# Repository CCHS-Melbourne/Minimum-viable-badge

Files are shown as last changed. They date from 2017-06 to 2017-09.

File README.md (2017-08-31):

Minimum Viable Badge - Just the facts.
=============

This project is designed to be the absolute minimum number of components to do a badge.

[Schematic Design](Minimum-viable-schematic.pdf?raw=true "Schematic")

FEATURES
--------

* ESP32 based.
* CP2102 USB to serial.
* eInk Display.

CREDITS
------------

Made at hackmelbourne.org!

This project was designed by the 2018 linux.conf.au Open Hardware Team!
 - [Bob Powers](https://github.com/rdpowers)
 - [John Spencer](https://github.com/mage0r)
 - [Angus Gratton](https://github.com/projectgus)
 - [Andy Gelme](https://github.com/geekscape)
 - [Jon Oxer](https://github.com/jonoxer)
 - [Mark Wolfe](https://github.com/wolfeidau)

SPECIAL THANKS
------------

To the HackMelbourne (CCHS, http://hackmelbourne.org) community of Melbourne, Australia.

To all other open-source developers whose countless hours supported every other aspect of this design.

DISTRIBUTION
------------
The specific terms of distribution of this project are governed by the
license referenced below. Please contact the copyright owner if you wish to modify the board for distribution. Please utilize this design for personal or research projects. Please acknowledge all contributors.

LICENSE
-------
Licensed under the TAPR Open Hardware License (www.tapr.org/OHL).
The "license" sub-folder also contains a copy of this license in plain text format.

Copyright John Spencer, Bob Powers, Angus Gratton, Andy Gelme, Jon Oxer, Mark Wolfe 2017

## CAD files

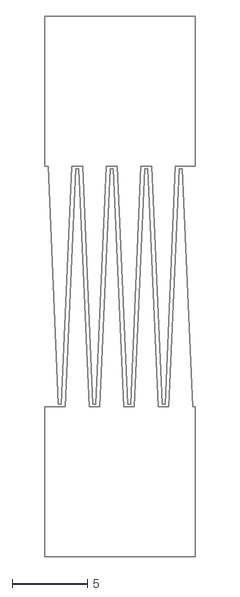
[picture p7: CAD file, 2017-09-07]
models/short-button.dxf
10.0 x 36.0

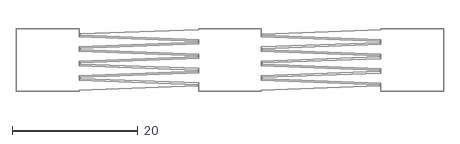
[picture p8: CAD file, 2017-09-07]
models/long-button.dxf
68.0 x 10.0

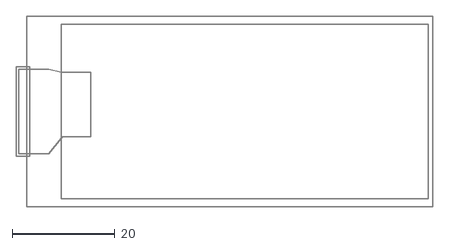
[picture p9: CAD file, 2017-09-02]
models/eink.2.0.dxf
81.1 x 37.0

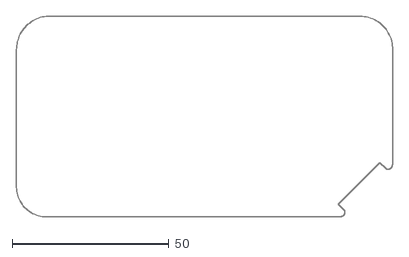
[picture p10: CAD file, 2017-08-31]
models/outline.2.0.dxf
120.0 x 64.0

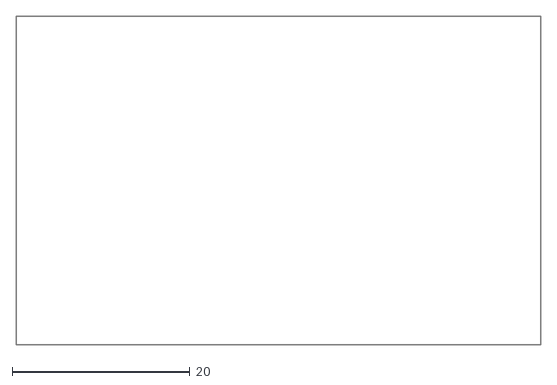
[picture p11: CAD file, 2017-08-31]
models/battery.2.0.dxf
59.0 x 37.0

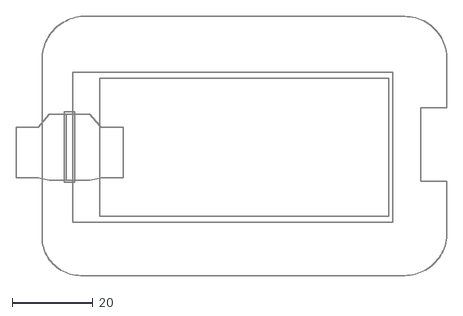
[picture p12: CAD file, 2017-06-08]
models/outline.dxf
106.4 x 64.0

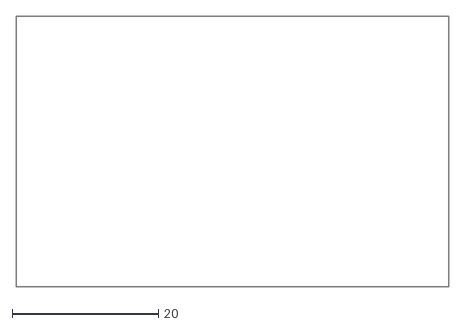
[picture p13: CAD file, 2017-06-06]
models/small Battery.dxf
59.0 x 37.0

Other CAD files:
models/outline-2.skp
models/outline.skp

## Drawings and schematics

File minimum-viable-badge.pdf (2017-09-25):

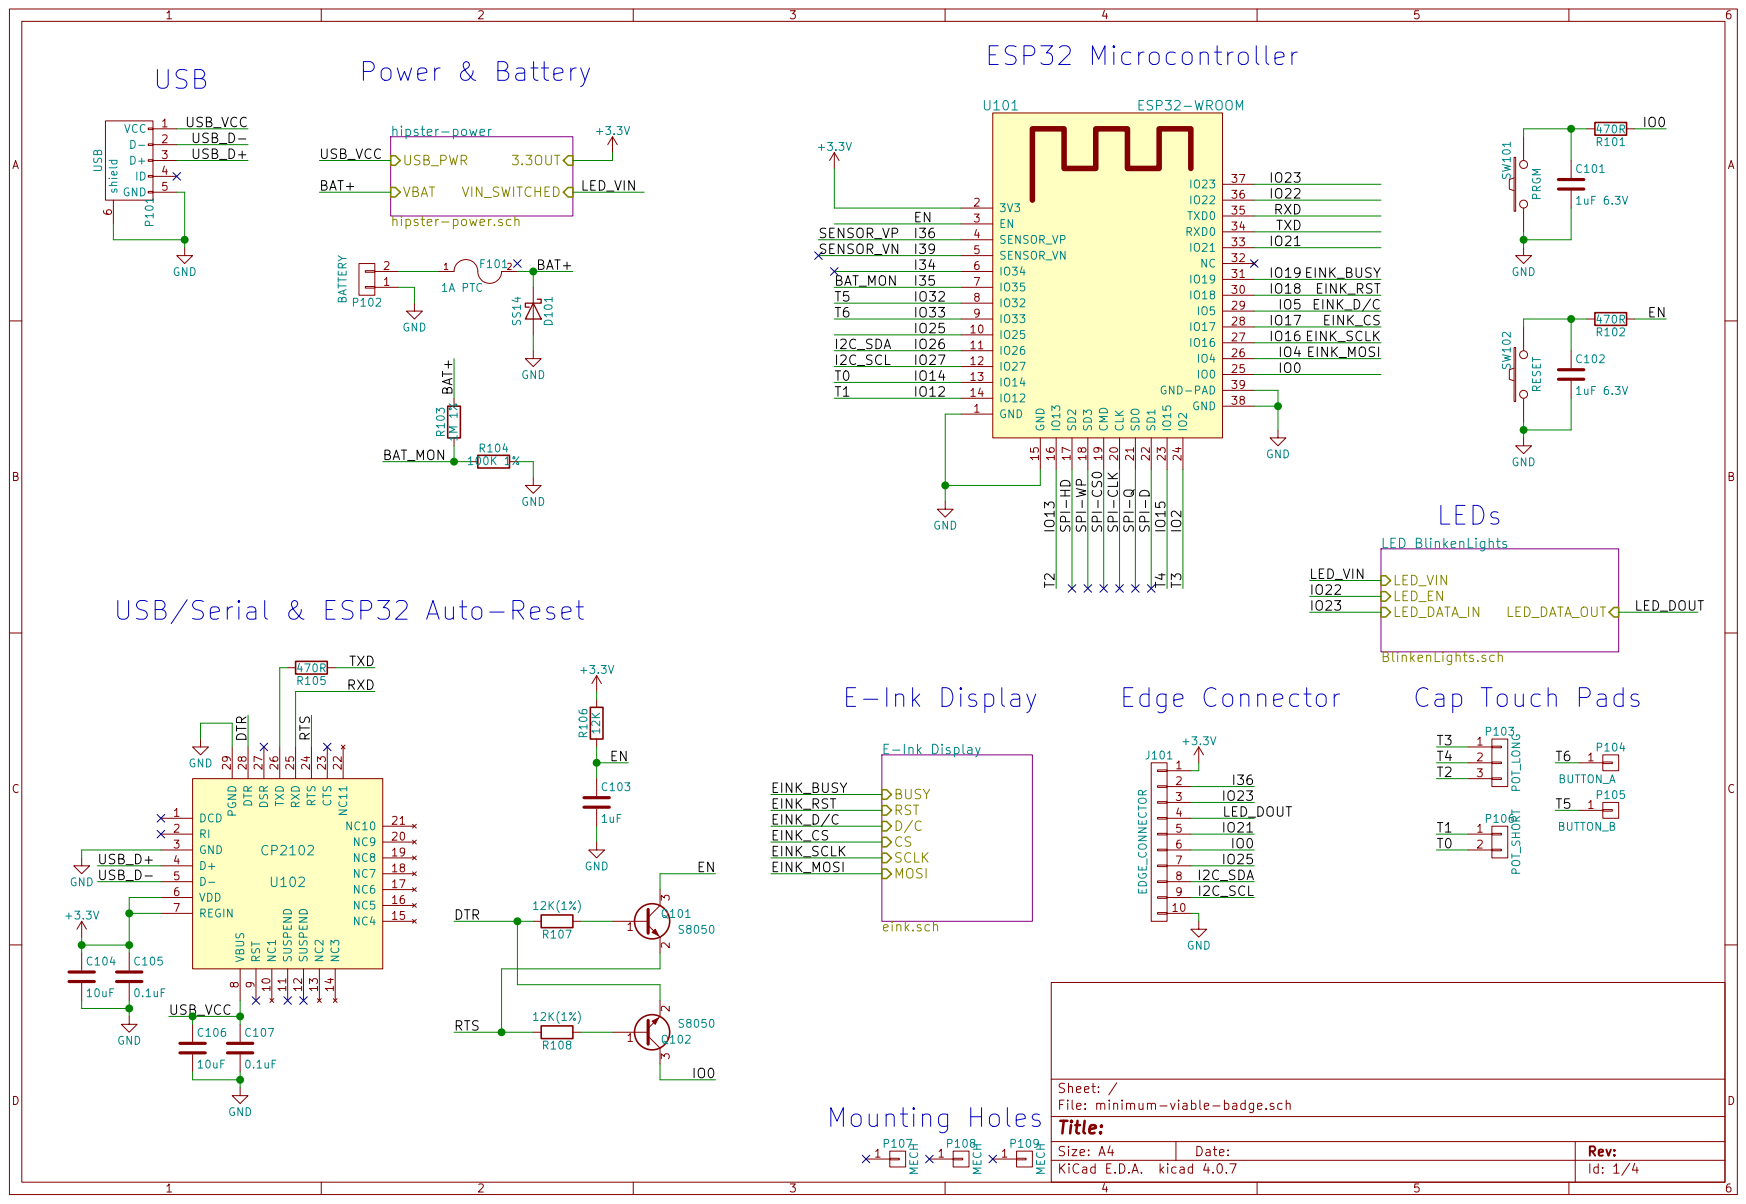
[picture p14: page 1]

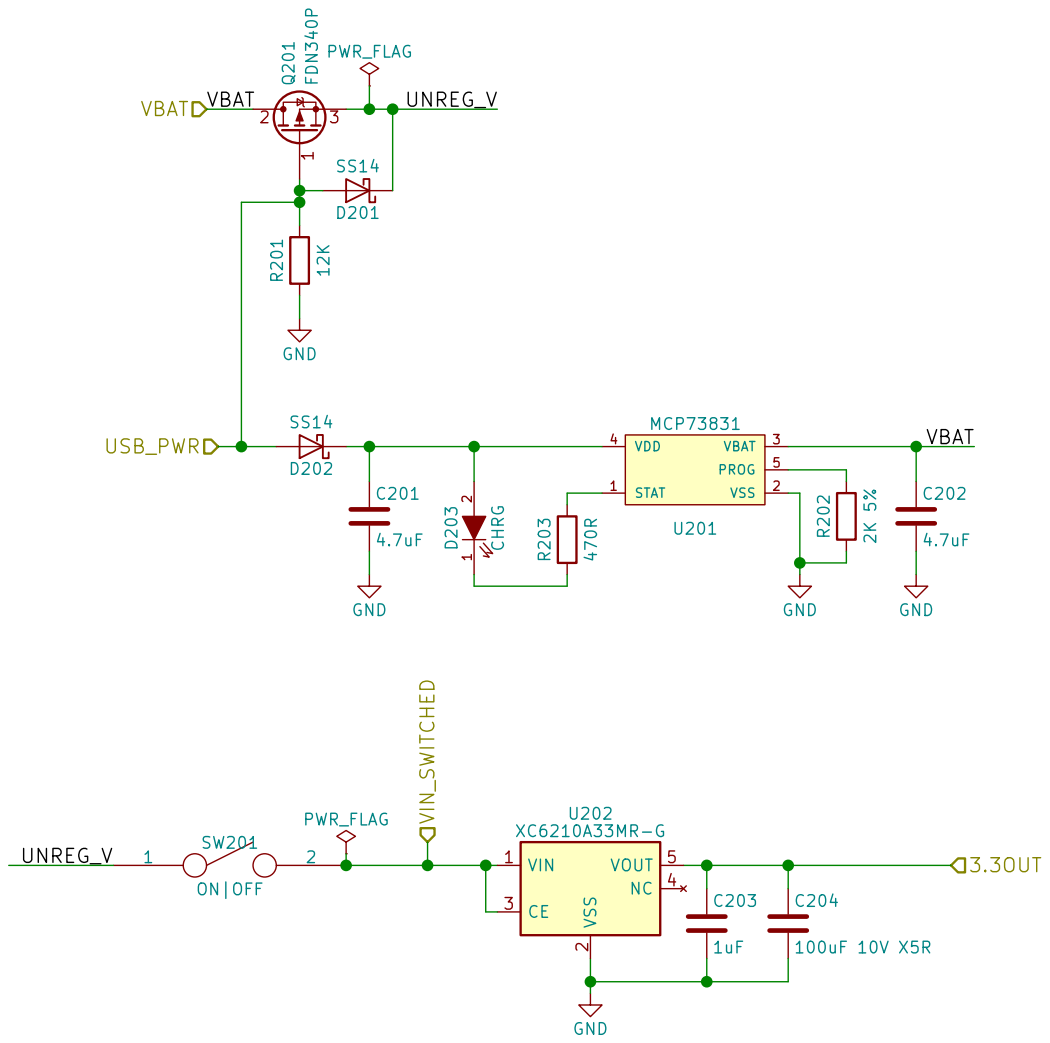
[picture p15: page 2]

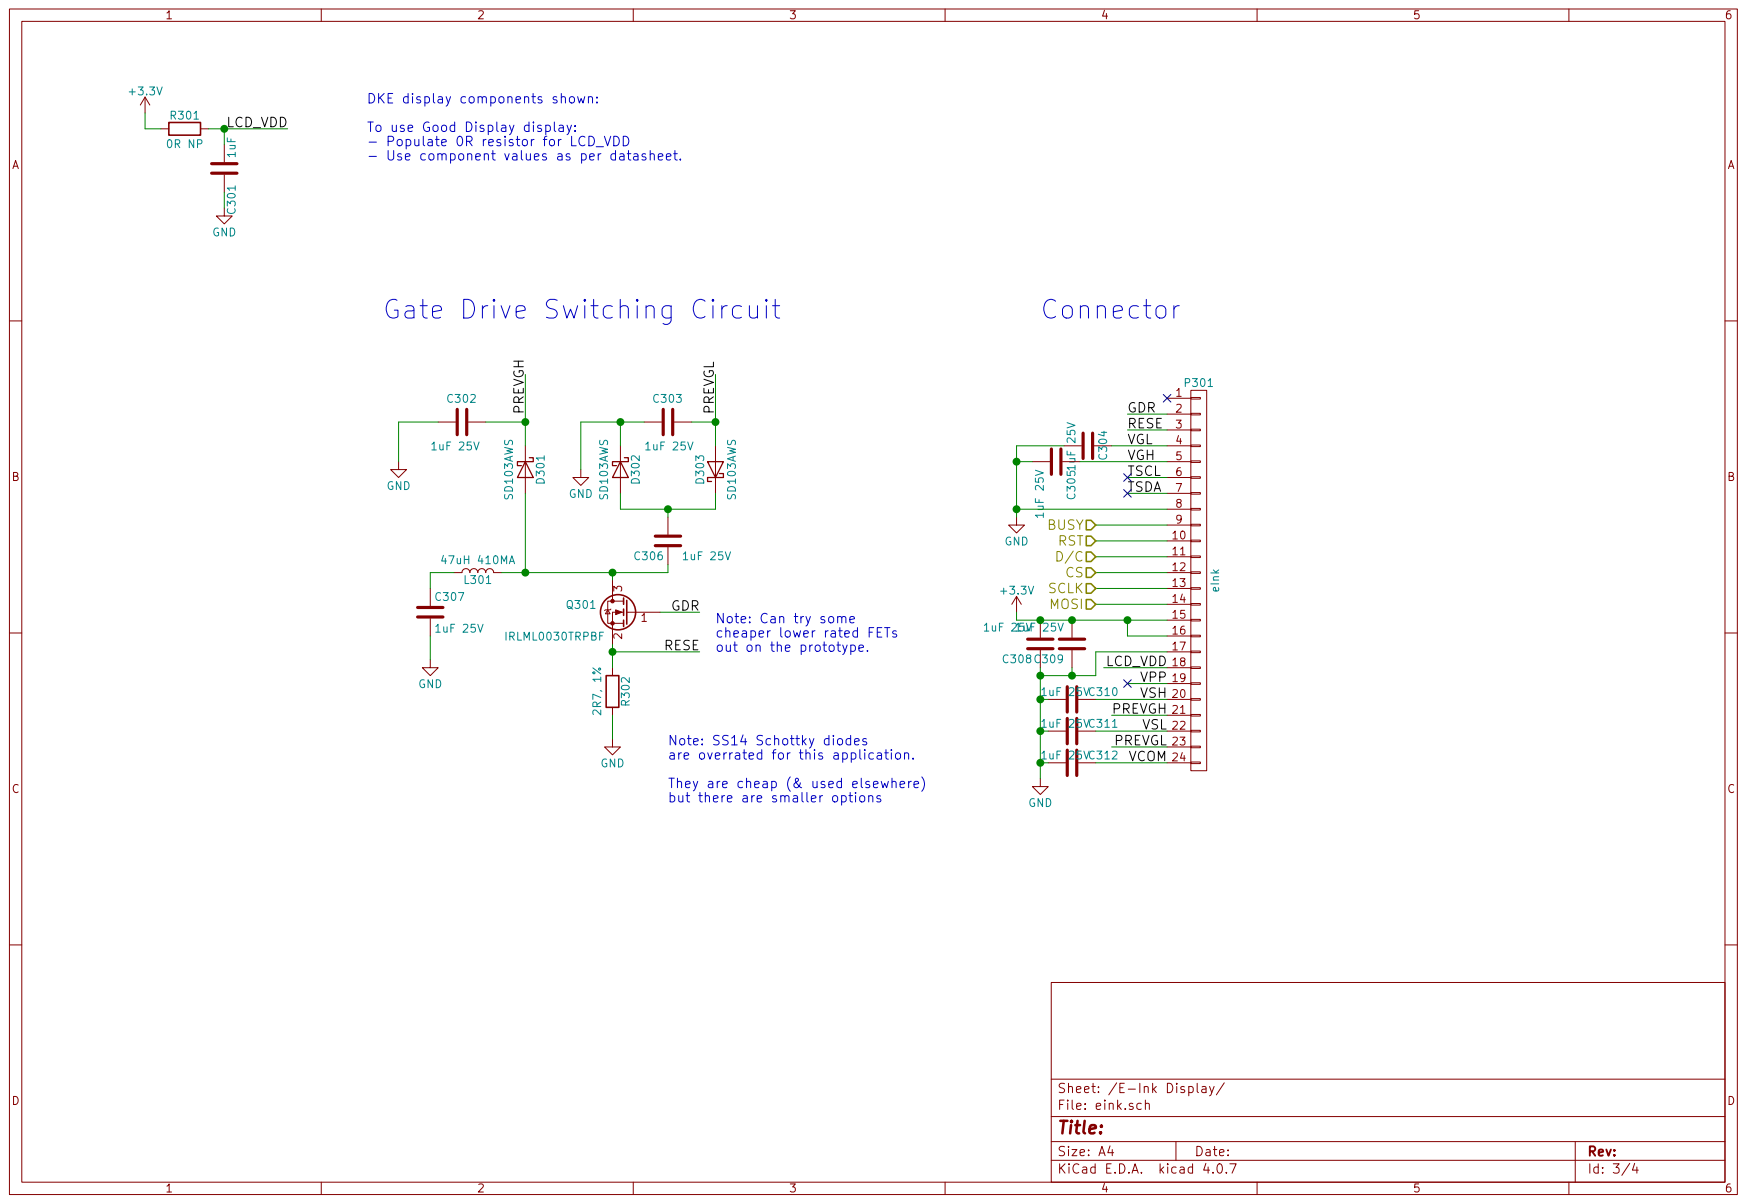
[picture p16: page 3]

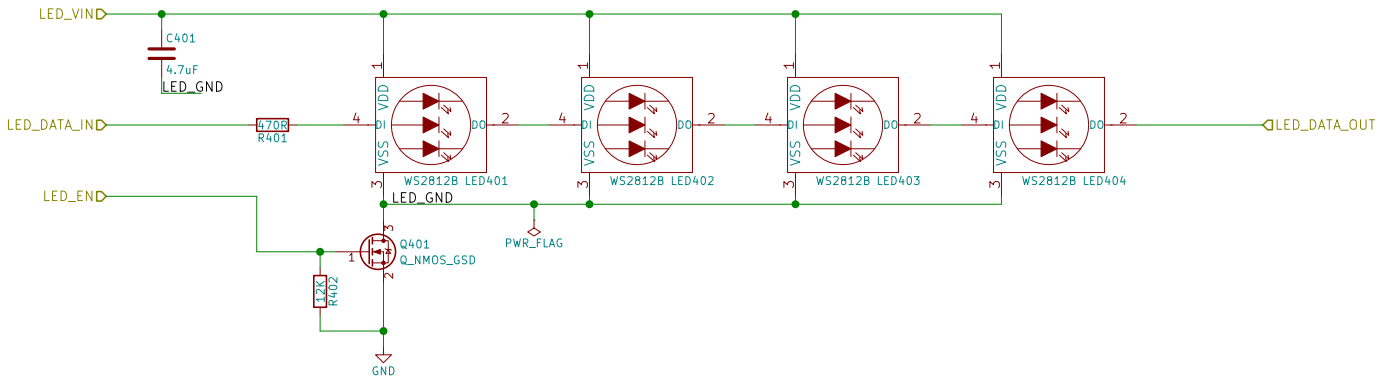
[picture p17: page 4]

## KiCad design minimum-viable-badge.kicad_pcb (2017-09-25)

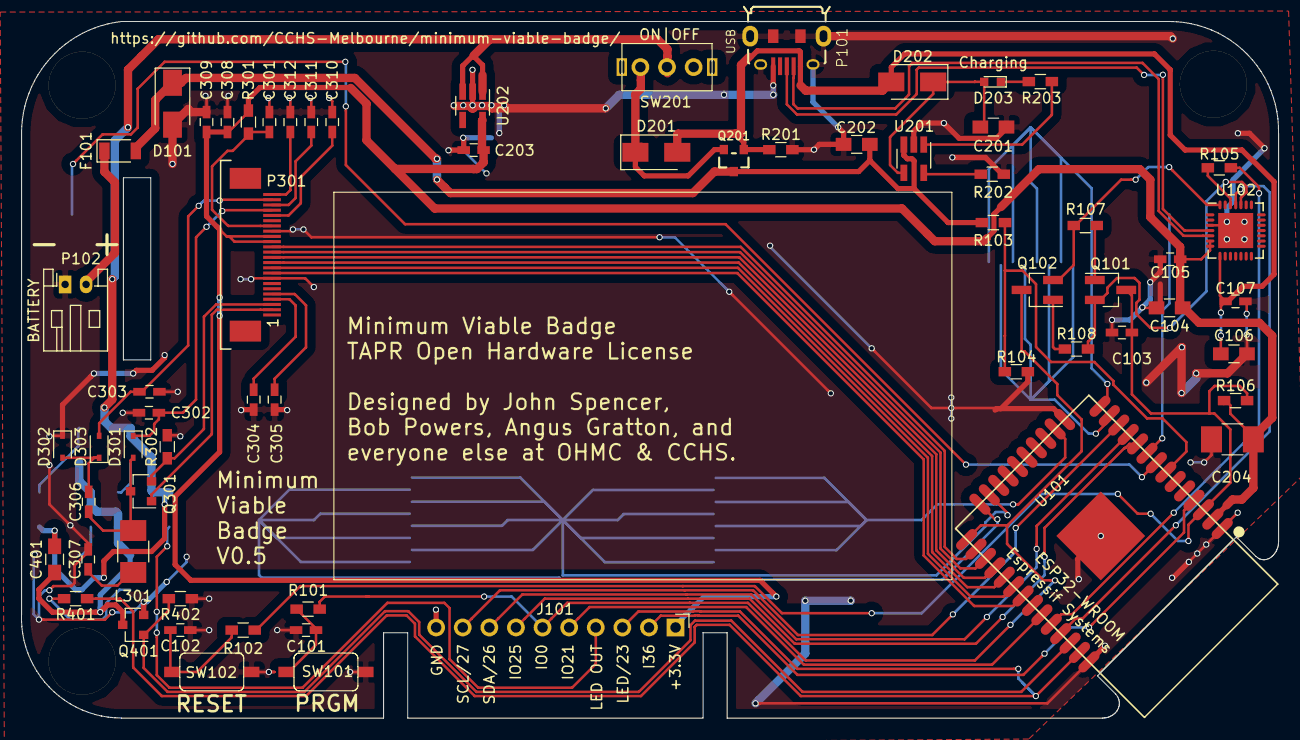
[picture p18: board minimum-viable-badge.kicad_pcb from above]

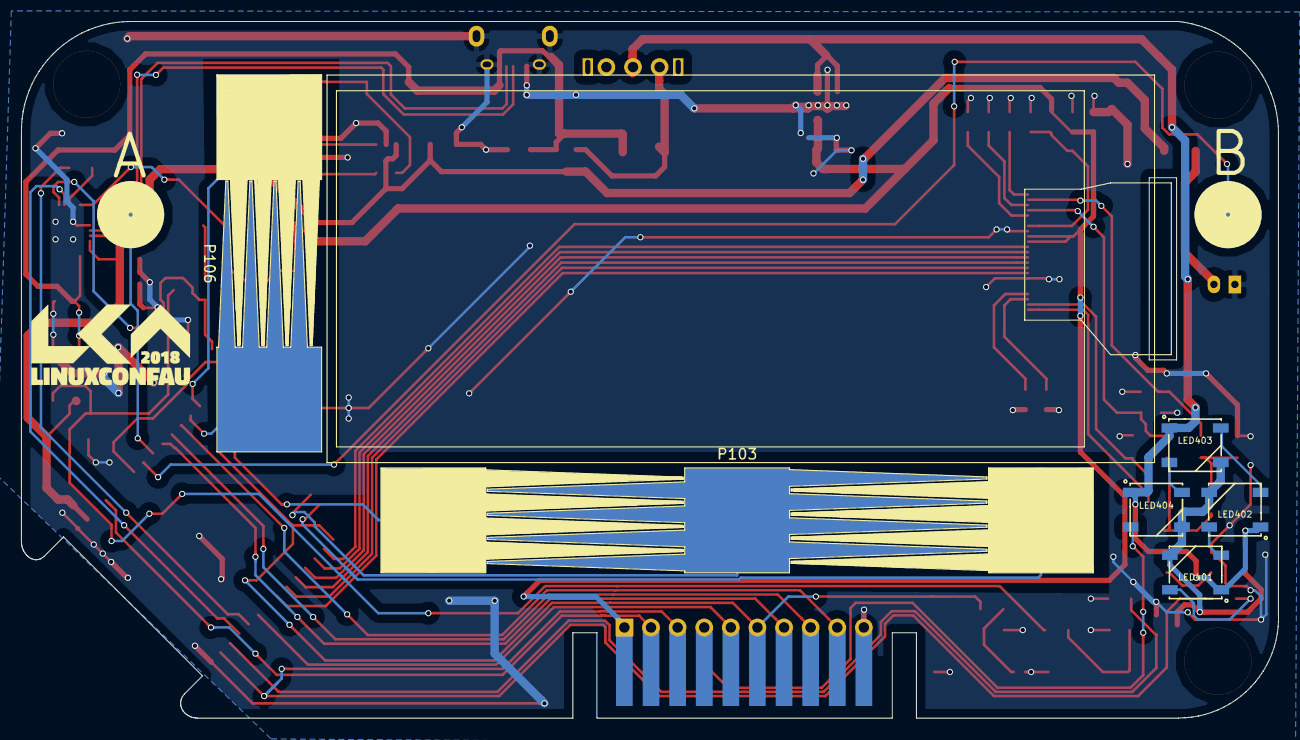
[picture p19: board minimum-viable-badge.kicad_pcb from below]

Board: 2 copper layers, 120.0 x 66.5 mm, 75 parts (8 on the bottom side), 64 nets.

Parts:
C101, C102: 1uF 6.3V; C_0603_HandSoldering
C103, C203, C301: 1uF; C_0603_HandSoldering
C104, C106: 10uF; C_0805_HandSoldering
C105, C107: 0.1uF; C_0603_HandSoldering
C201, C202, C401: 4.7uF; C_0805_HandSoldering
C204: 100uF 10V X5R; C_1210_HandSoldering
C302, C303, C304, C305, C306, C307, C308, C309, C310, C311, C312: 1uF 25V; C_0603_HandSoldering
D101, D201, D202: SS14; D_SMA
D203: CHRG; LED_0603
D301, D302, D303: SD103AWS; D_SOD-323
F101: 1A PTC; D_1206
J101: EDGE_CONNECTOR; Edge_Connector_S20-2.54-5_bottomsideonly
L301: 47uH 410MA; C_1210_HandSoldering
LED401, LED402, LED403, LED404: WS2812B
P101: USB; USB-MICRO-5pin_PTHMOUNT-Amphenol.10118194-0001LF
P102: BATTERY; JST_PH_S2B-PH-K_02x2.00mm_Angled
P103: POT_LONG; sense_long
P104: BUTTON_A; buttons
P105: BUTTON_B; buttons
P106: POT_SHORT; sense_short
P107, P108, P109: MECH; MountingHole_3.2mm_M3_Pad
P301: eInk; FPC_0.5mm_Pitch_24_Pin
Q101, Q102: S8050; SOT-23_Handsoldering
Q201: FDN340P; SOT23_FET
Q301: IRLML0030TRPBF; SOT-23
Q401: Q_NMOS_GSD; SOT-23
R101, R102, R105, R203, R401: 470R; R_0603_HandSoldering
R103: 1M 1%; R_0603_HandSoldering
R104: 100K 1%; R_0603_HandSoldering
R106, R201, R402: 12K; R_0603_HandSoldering
R107, R108: 12K(1%); R_0603_HandSoldering
R202: 2K 5%; R_0603_HandSoldering
R301: 0R; R_0603_HandSoldering
R302: 2R7, 1%; R_0603_HandSoldering
SW101: PRGM; K2-1107st
SW102: RESET; K2-1107st
SW201: ON|OFF; SK12D07VG3
U101: ESP32-WROOM
U102: CP2102; QFN-28-1EP_5x5mm_Pitch0.5mm
U201: MCP73831; SOT-23-5_HandSoldering
U202: XC6210A33MR-G; SOT-23-5_HandSoldering

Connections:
+3V3: C104.1, C105.1, C203.1, C204.1, C308.2, C309.2, J101.1, P301.15, P301.16, R106.2, R301.1, U101.2, U102.6, U102.7, U202.5
/BAT+: C202.1, D101.1, F101.2, Q201.2, R103.2, U201.3
/BAT_MON: R103.1, R104.1, U101.7
/DTR: Q102.2, R107.2, U102.28
/E-Ink Display/GDR: P301.2, Q301.1
/E-Ink Display/LCD_VDD: C301.2, P301.18, R301.2
/E-Ink Display/PREVGH: C302.1, D301.1, P301.21
/E-Ink Display/PREVGL: C303.1, D303.2, P301.23
/E-Ink Display/RESE: P301.3, Q301.2, R302.1
/E-Ink Display/VCOM: C312.1, P301.24
/E-Ink Display/VGH: C305.1, P301.5
/E-Ink Display/VGL: C304.1, P301.4
/E-Ink Display/VSH: C310.1, P301.20
/E-Ink Display/VSL: C311.1, P301.22
/EINK_BUSY: P301.9, U101.31
/EINK_CS: P301.12, U101.28
/EINK_D/C: P301.11, U101.29
/EINK_MOSI: P301.14, U101.26
/EINK_RST: P301.10, U101.30
/EINK_SCLK: P301.13, U101.27
/EN: C103.1, Q101.3, R102.1, R106.1, U101.3
/I2C_SCL: J101.9, U101.12
/I2C_SDA: J101.8, U101.11
/I36: J101.2, U101.4
/IO0: J101.6, Q102.3, R101.1, U101.25
/IO2: P103.1, U101.24
/IO12: P106.1, U101.14
/IO13: P103.3, U101.16
/IO14: P106.2, U101.13
/IO15: P103.2, U101.23
/IO21: J101.5, U101.33
/IO22: Q401.1, R402.1, U101.36
/IO23: J101.3, R401.2, U101.37
/IO25: J101.7, U101.10
/IO32: P105.1, U101.8
/IO33: P104.1, U101.9
/LED BlinkenLights/LED_GND: C401.2, LED401.3, LED402.3, LED403.3, LED404.3, Q401.3
/LED_DOUT: J101.4, LED404.2
/LED_VIN: C401.1, LED401.1, LED402.1, LED403.1, LED404.1, SW201.2, U202.1, U202.3
/RTS: Q101.2, R108.2, U102.24
/RXD: U101.35, U102.25
/TXD: R105.1, U101.34
/USB_D+: P101.3, U102.4
/USB_D-: P101.2, U102.5
/USB_VCC: C106.1, C107.1, D201.2, D202.2, P101.1, Q201.1, R201.1, U102.8
/hipster-power/UNREG_V: D201.1, Q201.3, SW201.1
GND: C101.2, C102.2, C103.2, C104.2, C105.2, C106.2, C107.2, C201.2, C202.2, C203.2, C204.2, C301.1, C302.2, C303.2, C304.2, C305.2, C307.2, C308.1, C309.1, C310.2, C311.2, C312.2, D101.2, D302.1, J101.10, P101.5, P101.6, P102.1, P301.8, P301.17, Q401.2, R104.2, R201.2, R202.2, R302.2, R402.2, SW101.1, SW102.1, U101.1, U101.15, U101.38, U101.39, U102.3, U102.29, U201.2, U202.2
unnamed: C101.1, R101.2, SW101.2
unnamed: C102.1, R102.2, SW102.2
unnamed: C201.1, D202.1, D203.2, U201.4
unnamed: C306.1, D301.2, L301.2, Q301.3
unnamed: C306.2, D302.2, D303.1
unnamed: C307.1, L301.1
unnamed: D203.1, R203.2
unnamed: F101.1, P102.2
unnamed: LED401.2, LED402.4
unnamed: LED401.4, R401.1
unnamed: LED402.2, LED403.4
unnamed: LED403.2, LED404.4
unnamed: Q101.1, R107.1
unnamed: Q102.1, R108.1
unnamed: R105.2, U102.26
unnamed: R202.1, U201.5
unnamed: R203.1, U201.1

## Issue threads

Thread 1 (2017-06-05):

MCP6002 Pinout

rdpowers, 2017-06-05:
Pins 5&6 (exclusive-or 3&4) need to be swapped for correct operation of charge circuitry.
See: https://github.com/CCHS-Melbourne/iotuz-esp32-hardware/issues/41

mage0r, 2017-06-06:
Fixed.  We don't really need the MCP6002 so that whole section was simplified.

Closed 2017-06-06.

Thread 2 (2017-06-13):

S8050 pinout is wrong.

rdpowers, 2017-06-13:
Your auto-reset circuitry, and probably USB comms, aren't going to work. It should be:
1) Base
2) Emitter
3) Collector

but you have
1) Emitter
2) Base
3) Collector

Same as https://github.com/CCHS-Melbourne/iotuz-esp32-hardware/issues/10

mage0r, 2017-06-13:
Damnit.  That library caught me again.

Closed 2017-06-13.

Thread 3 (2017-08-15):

Supporting caps for eink display

mage0r, 2017-08-15:
Feels like we should have some.

Check the SHA2017 badge and look at what it's circuit involves.

file:///C:/Users/t27981/Downloads/sha2017_rev0_1_0_dev_schematic.pdf

projectgus, 2017-09-19:
Fixed in proto3.

Closed 2017-09-19.

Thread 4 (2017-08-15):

VBAT wiring to UNREG_V will cause problems.

mage0r, 2017-08-15:
from @projectgus

VBAT is directly fed to UNREG_V means that the ESP32 won't be able to start up if there's no battery connected, and the ESP32 will discharge the battery when running even when USB is connected. It may also have some implications on the battery lifespan as the charge chip won't be able to properly regulate the charging current (I don't know what the implications of this are).

projectgus, 2017-09-19:
Fixed in proto3.

Closed 2017-09-19.

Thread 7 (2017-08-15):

position of eink fitting is too low.

mage0r, 2017-08-15:

mage0r, 2017-09-04:
Eink position has been changed.
Corrected footprint in f85f47793a15941b2dda4656cb43bf8c77c8c573

Closed 2017-09-04.

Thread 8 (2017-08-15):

Battery position is not helpful.

mage0r, 2017-08-15:

projectgus, 2017-08-23:
Also suggest using a keyed battery connector rather than bare pins.

mage0r, 2017-09-04:
Battery is opened in #16

Battery moved in f85f47793a15941b2dda4656cb43bf8c77c8c573

Closed 2017-09-04.

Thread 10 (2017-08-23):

GPIO0 not right for captouch

projectgus, 2017-08-23:
Because of other connections (I think), it's impossible to get a reading back from the captouch channel on GPIO0.

(The other ones work pretty nicely!)

mage0r, 2017-09-04:
GPIO no longer a cap-touch pin.

Closed 2017-09-04.

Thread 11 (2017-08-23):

Captouch sliders are a bit short

projectgus, 2017-08-23:
The captouch sliders seem to work pretty nicely, but they are a bit short (at least for my large-ish fingers) to distinguish very much movement across the surface of the slider.

mage0r, 2017-09-04:
Sliders have been replaced with larger models.  Also, they should be masked off.

Leaving ticket open until we have inspected the boards.

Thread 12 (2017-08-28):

Power Schematic PFET Replacement Of BJT

rdpowers, 2017-08-28:
On commit 496802f80ed5d8f414428e2122202bfbdc3e1292, the S8050 on the hipster power sub need to be an appropriately picked PFET.

Closed 2017-08-28.

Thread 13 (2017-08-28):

Capacitors need types & voltage ratings

projectgus, 2017-08-28:
To avoid surprises at the assembly house.

Do not need to be on schematic, can be on BoM. But need to be somewhere.

projectgus, 2017-08-28:
Apologies, I see most of them have this information in the extra component data. But some still need filling in.

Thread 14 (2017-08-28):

e-ink gate driving power circuitry is missing

projectgus, 2017-08-28:
For Good-Display GDEW029x models a gate drive circuit is required between pins PREVGH, PREVGL, GDR, RESE.

For Dalian DEPG0290B01, the drive circuit is very similar but looks like it connects to different pins.

Closed 2017-08-30.

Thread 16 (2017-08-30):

Battery connector

projectgus, 2017-08-30:
Should be keyed & something which is common to find on flat 3.7V lithium polymer batteries

projectgus, 2017-09-13:
Done, JST PH2.

Closed 2017-09-13.

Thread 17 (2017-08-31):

Reset and program buttons

mage0r, 2017-08-31:
Don't sound very minimal!

mage0r, 2017-09-04:
We're keeping em!

Closed 2017-09-04.

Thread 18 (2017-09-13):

Battery Overlay

rdpowers, 2017-09-13:
Has wrong polarity.

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

Closed 2017-09-13.

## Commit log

2017-06-04 Initial commit
    Basic Schematic is already in place.
    [ESP32-Footprints.kicad_pcb, ESP32-Footprints.sch, hipster-power.sch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]
2017-06-04 Added readme and pdf schematic
2017-06-05 Now with less Hipster :(
    [hipster-power.sch, minimum-viable-badge.kicad_pcb, minimum-viable-badge.sch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]
2017-06-06 Updated cap sense.
    [hipster-power.sch, minimum-viable-badge.kicad_pcb, minimum-viable-badge.sch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]
2017-06-06 Minor changes to the pcb.
    Still testing ideas.
    [minimum-viable-badge.kicad_pcb, small Battery.dxf]
2017-06-07 More pcb work
    [minimum-viable-badge.kicad_pcb, minimum-viable-badge.sch, outline.skp]
2017-06-08 Updated pcb layout.
    [minimum-viable-badge.kicad_pcb, minimum-viable-badge.sch, outline.dxf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]
2017-06-13 Damnit. S8050 backwards
    Thanks https://github.com/rdpowers. Fixes #2
    [hipster-power.sch, minimum-viable-badge.kicad_pcb, minimum-viable-badge.sch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]
2017-06-13 Added some digikey links.
    [hipster-power.sch, minimum-viable-badge.sch]
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2017-08-25 updated touch sensors
    [hipster-power.sch, minimum-viable-badge.kicad_pcb, minimum-viable-badge.sch]
2017-08-26 Added eInk decoupling caps.
    [hipster-power.sch, minimum-viable-badge.sch]
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2017-08-28 Extra touch buttons
    and edge connector!
    [hipster-power.sch, minimum-viable-badge.sch]
2017-08-28 power: Swap BJT for FET in power selection circuit
    Went with FDN340P as used on ESPlant, but any appropriately rated FET will do.
    Closes #12
    [hipster-power.sch]
2017-08-28 Remove power LED
    Will reduce deep sleep power consumption to 1% or less of previous.
    Ref #6.
    [hipster-power.sch]
2017-08-28 Add capacitor to EN pin
    Prevents problems with auto-reset
    [minimum-viable-badge.sch]
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2017-08-30 Arrange & label schematic, pass ERC
    [eink.sch, hipster-power.sch, minimum-viable-badge.sch]
2017-08-30 Add e-ink gate drive circuitry
    Closes #14
    [eink.sch, hipster-power.sch, minimum-viable-badge.kicad_pcb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]
2017-08-31 New outlines for the larger badge
    [battery.2.0.dxf, eink.2.0.dxf, outline.2.0.dxf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]
2017-08-31 PCB new outline added
    [minimum-viable-badge.kicad_pcb]
2017-08-31 Set component footprints.
    [eink.sch, hipster-power.sch, minimum-viable-badge.sch]
2017-09-02 Placement started
    Predicting Bob will end up changing all this
    [eink.2.0.dxf, eink.sch, hipster-power.sch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]
2017-09-03 More footprint layout.
    [minimum-viable-badge.kicad_pcb]
2017-09-03 Minor updates to schematic components.
    [Pinmap.ods, eink.sch, hipster-power.sch]
2017-09-03 Picked inductor.
    [eink.sch]
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2017-09-03 Keeping everything in sync.
    [minimum-viable-badge.kicad_pcb]
2017-09-03 Updated footprint for buttons.
    [_saved_hipster-power.sch]
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2017-09-03 Updated to use new switch.
    [_saved_hipster-power.sch, hipster-power.sch, minimum-viable-badge.kicad_pcb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]
2017-09-03 Changed drive circuitry Schottky diodes to SOD323.
    [eink.sch]
2017-09-03 many more components added to the pcb
    [minimum-viable-badge.kicad_pcb]
2017-09-03 LCD pins routed to ESP32
    [minimum-viable-badge.kicad_pcb]
2017-09-03 broken lcd routes
    [minimum-viable-badge.kicad_pcb]
2017-09-03 Shuffling around our touch sensor pins.
    [minimum-viable-badge.sch]
2017-09-03 Hey, that looks like a board!
    [minimum-viable-badge.kicad_pcb]
2017-09-03 Minor updates.
    [minimum-viable-badge.kicad_pcb]
2017-09-03 Flipped is better.
    [minimum-viable-badge.kicad_pcb]
2017-09-03 Swap battery connector to JST PH 2.0
    [minimum-viable-badge.kicad_pcb, minimum-viable-badge.sch]
2017-09-03 Ground planes, power nets, move bulk cap close to ESP32
    [minimum-viable-badge.kicad_pcb]
2017-09-03 Add missing stitching vias on other side of eink data lines
    [minimum-viable-badge.kicad_pcb]
2017-09-06 Add SZLCSC part links
    [eink.sch, hipster-power.sch, minimum-viable-badge.sch]
2017-09-06 Swap C307 0603->0805
    [minimum-viable-badge.kicad_pcb]
2017-09-06 Rename power switch SK12D07VG5 -> SK12D07VG3
    [hipster-power.sch, minimum-viable-badge.kicad_pcb]
2017-09-07 Added edge connector and button silkscreen
    [long-button.dxf, minimum-viable-badge.kicad_pcb, minimum-viable-badge.sch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]
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2017-09-11 Change 3.3V reg to XC6210, enlarge board to move power switch
    [eink.sch, hipster-power.sch, minimum-viable-badge.kicad_pcb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]
2017-09-11 Fixed some connections. added vias
    [hipster-power.sch, minimum-viable-badge.kicad_pcb]
2017-09-11 Fixed edge layer.
    [minimum-viable-badge.kicad_pcb]
2017-09-11 Moved buttons around.
    This might work!
    [minimum-viable-badge.kicad_pcb]
2017-09-13 Fix power switch label
    Closes #19
    [minimum-viable-badge.kicad_pcb]
2017-09-13 Fix battery label polarity on silkscreen
    Closes #18
    [minimum-viable-badge.kicad_pcb]
2017-09-19 Correct e-ink connector direction, reposition & reroute board
    Closes #20
    [eink.sch, minimum-viable-badge.kicad_pcb, minimum-viable-badge.sch]
2017-09-19 Place ground plane over the horizontal touch slider
    [minimum-viable-badge.kicad_pcb]
2017-09-19 Move switchmode parts out from under battery. Partially routed...
    [minimum-viable-badge.kicad_pcb]
2017-09-19 Some updating of pinmap before branch, need updating again.
    [Pinmap.ods]
2017-09-19 Making some progress on moving the battery connector & boost converter.
    [minimum-viable-badge.kicad_pcb]
2017-09-19 Some prospective positions & routing. Needs a bit of work, but looking much better.
    [minimum-viable-badge.kicad_pcb]
2017-09-19 I don't know what wasn't saved, but it wasn't major.
    [minimum-viable-badge.kicad_pcb]
2017-09-19 Finish routing changes, add some labels
    [minimum-viable-badge.kicad_pcb]
2017-09-19 Move credits to under battery
    [minimum-viable-badge.kicad_pcb]
2017-09-19 Silkscreen cleanup
    [minimum-viable-badge.kicad_pcb]
2017-09-20 Moved eInk bus off of opposite of back slider.
    [minimum-viable-badge.kicad_pcb]
2017-09-24 Add WS2812Bs for Blinkenlights
    [BlinkenLights.sch, eink.sch, hipster-power.sch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]
2017-09-24 Route LEDs, make edge connector one sided with mounting slots
    [hipster-power.sch, minimum-viable-badge.kicad_pcb, minimum-viable-badge.sch]
2017-09-24 Swap to use DEPG0290BNS75AF0-compatible components
    [eink.sch, minimum-viable-badge.kicad_pcb]
2017-09-24 Fix J101 label
    [minimum-viable-badge.kicad_pcb]
2017-09-24 Fix some orphaned stitching vias
    [minimum-viable-badge.kicad_pcb]
2017-09-24 More stitching via cleanup
    [minimum-viable-badge.kicad_pcb]
2017-09-24 Add more ground plane around the LEDs
    [minimum-viable-badge.kicad_pcb]
2017-09-25 Cosmetic tidy up
    [minimum-viable-badge.kicad_pcb]
